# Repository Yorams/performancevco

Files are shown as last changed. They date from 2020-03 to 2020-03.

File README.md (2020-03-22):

# Performance VCO
Eurorack version of LMNC Performance VCO based on the AS3340 VCO IC

Link to original project: https://www.lookmumnocomputer.com/projects#/1222-performance-vco

Included is also the BOM with Farnell order codes and the links from the original project.

If you are intrested in ordering some PCB's for a small price i can help you with that. Send me an email: yscheer@gmail.com

You can get the arduino firmware for the tuner here: https://github.com/josbouten/Tune-O-Matic

# Some Images
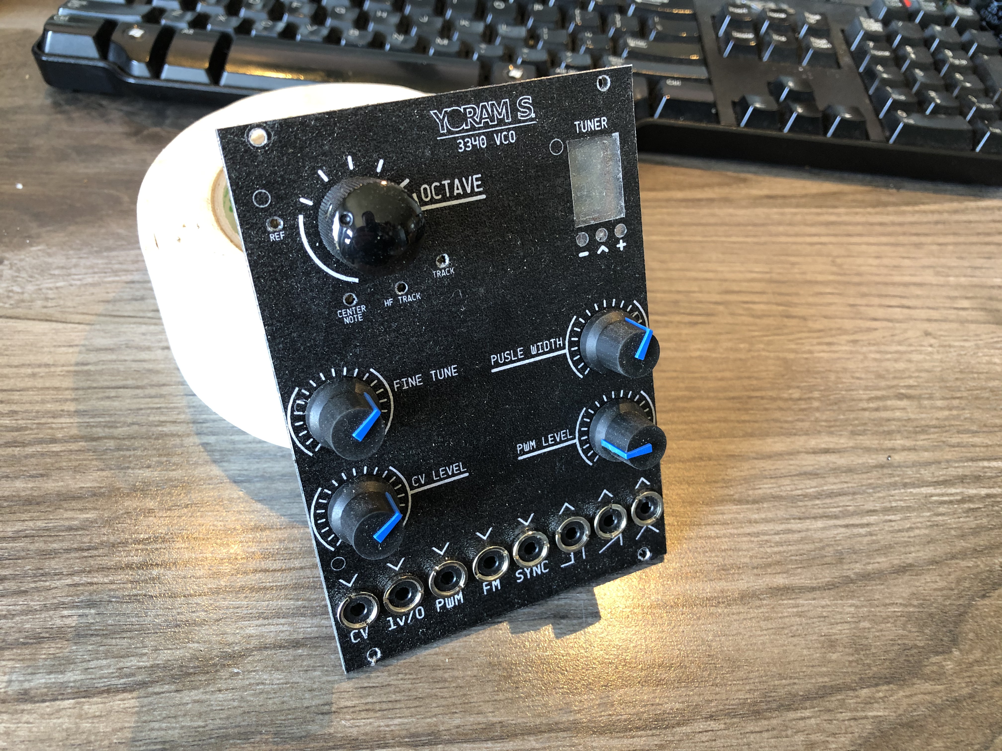
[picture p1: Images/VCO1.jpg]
VCO 1

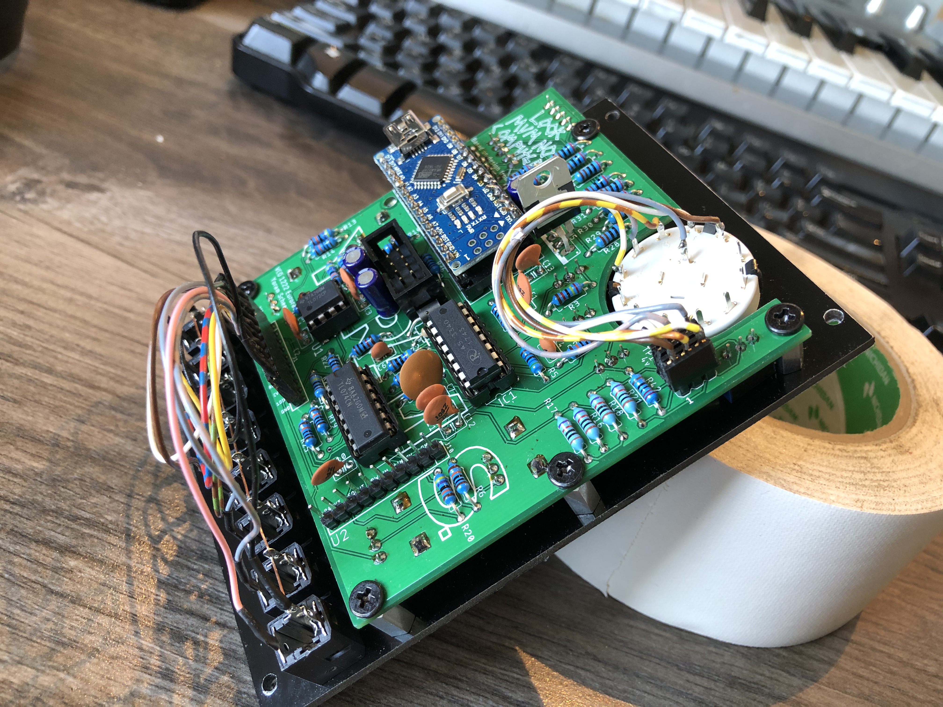
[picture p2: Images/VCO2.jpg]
VCO 2

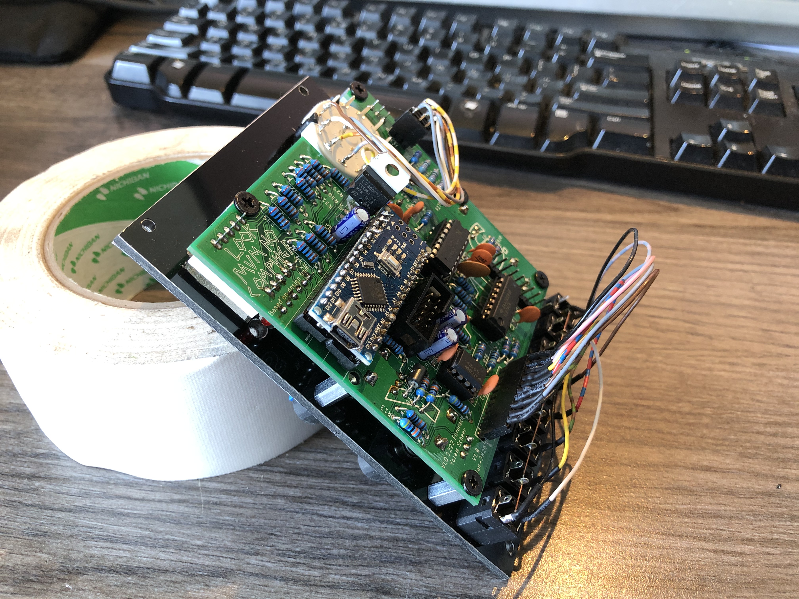
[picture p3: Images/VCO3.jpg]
VCO 3

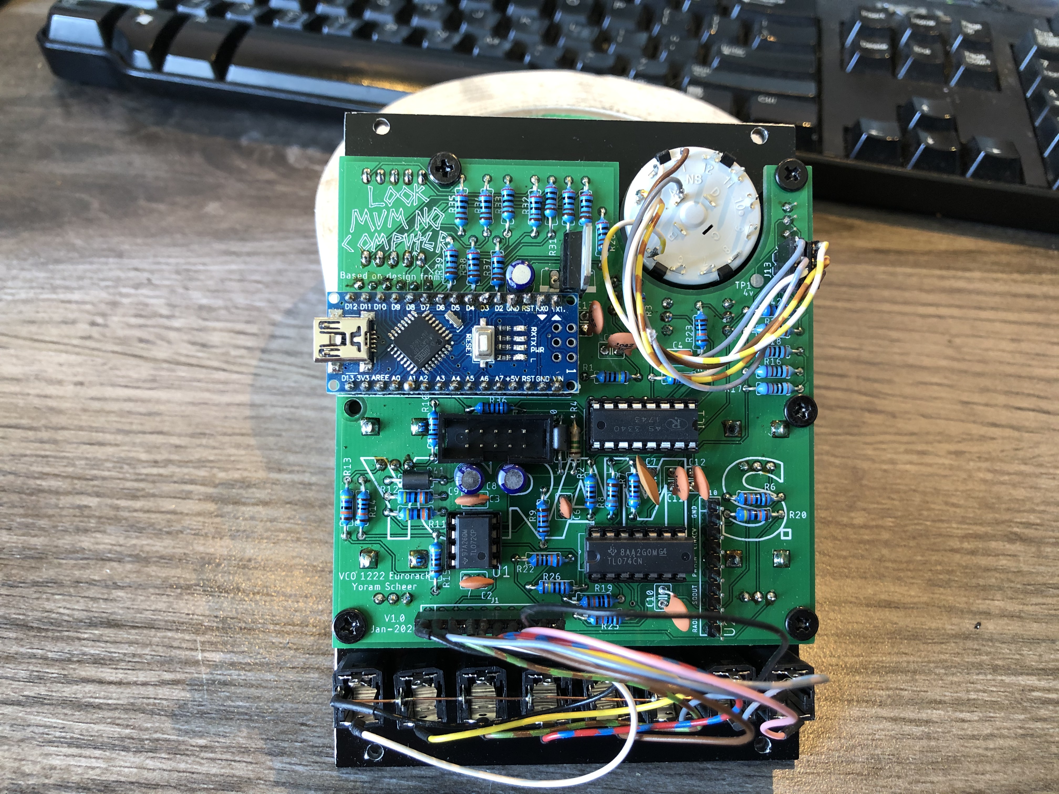
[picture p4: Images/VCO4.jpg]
VCO 4


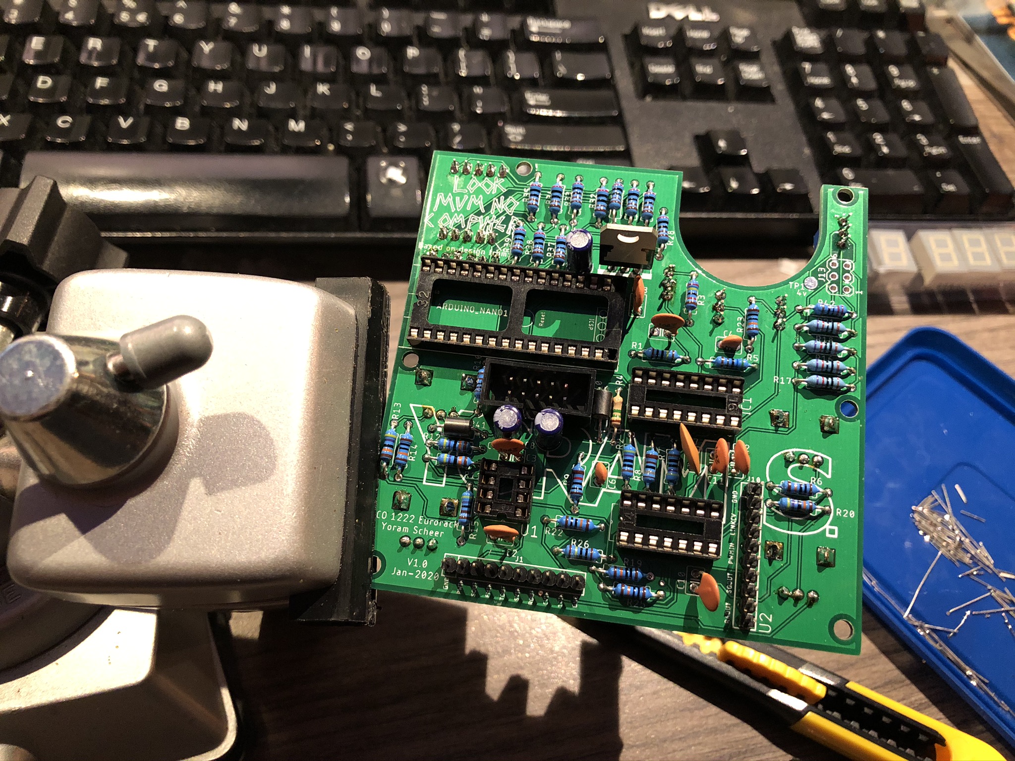
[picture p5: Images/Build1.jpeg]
Build 1

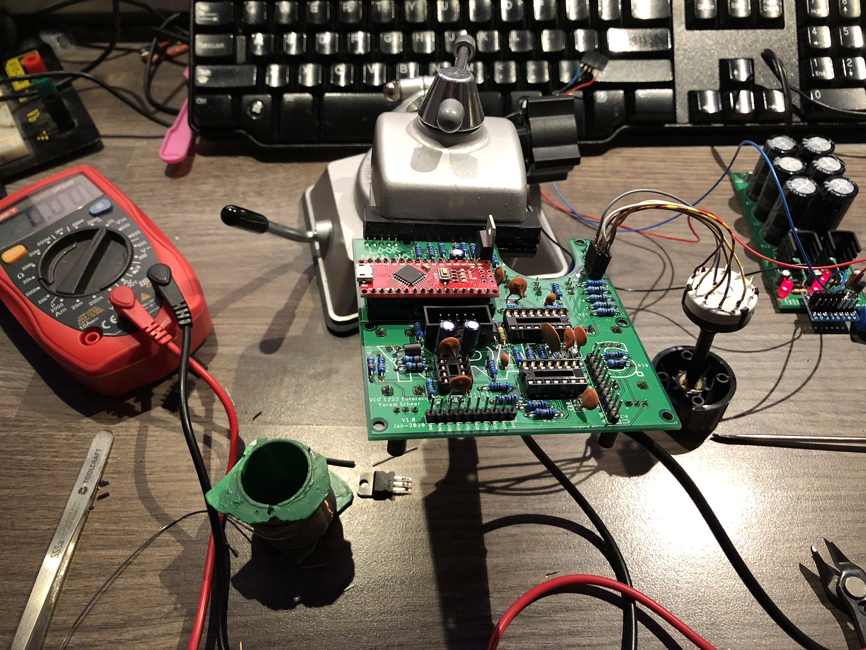
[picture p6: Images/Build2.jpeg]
Build 2

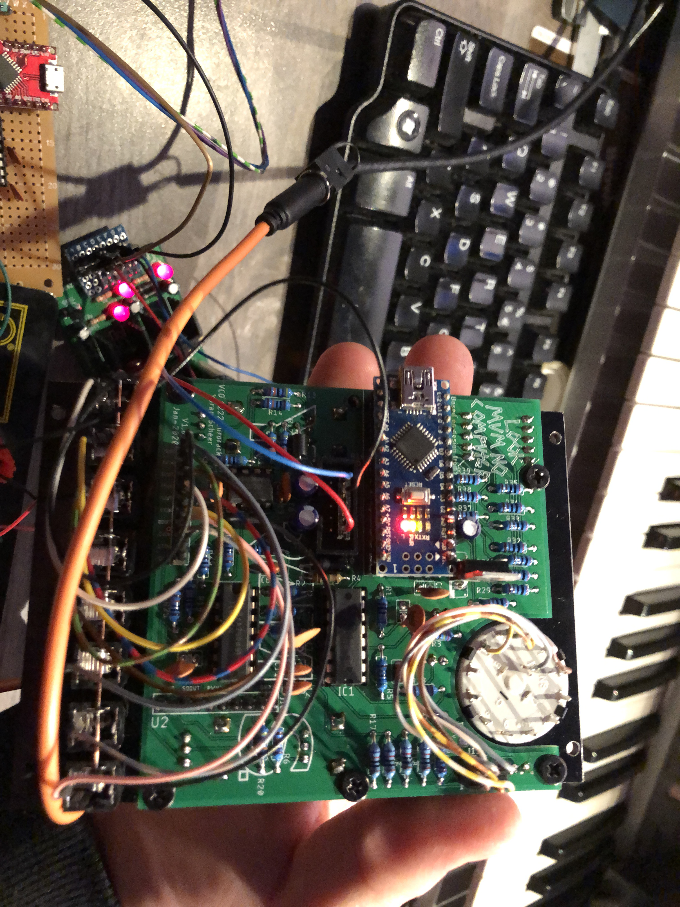
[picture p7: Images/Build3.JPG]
Build 3


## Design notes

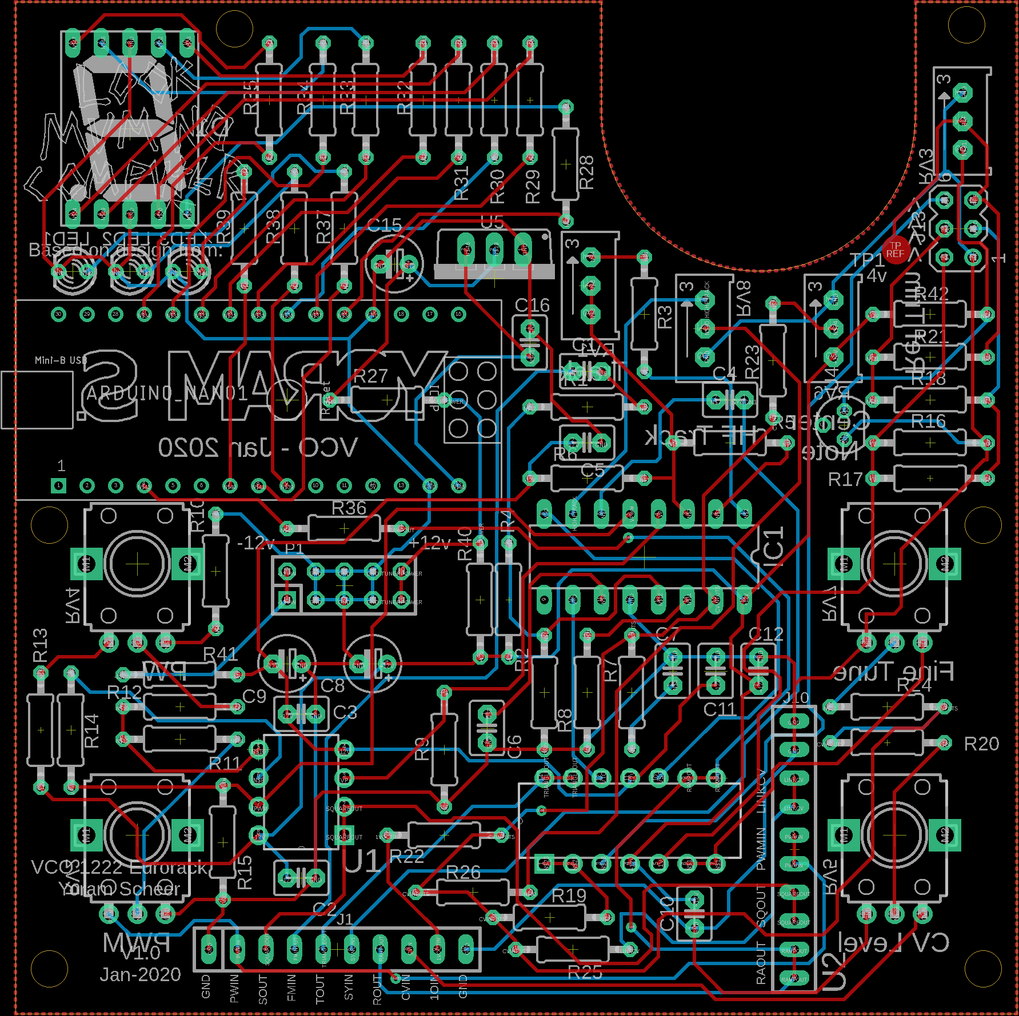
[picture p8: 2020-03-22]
Board.png

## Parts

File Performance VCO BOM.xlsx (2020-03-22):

Designator | Description | Amount | Value | Farnell code |  | Alternative supplier
C4,C6 | Ceramic Capacitor | 2 | 1nf | 9411828 |  | https://www.rapidonline.com/suntan-ts15001h102ksbpa0r-1nf-10-50v-y5p-2-5mm-ceramic-disc-capacitor-08-0200
C7 | Ceramic Capacitor | 1 | 10nf | 1827843 |  | https://www.rapidonline.com/suntan-ts15001h102ksbpa0r-1nf-10-50v-y5p-2-5mm-ceramic-disc-capacitor-08-0200
C1,C2,C3,C5,C10,C11,C12,C16 | Ceramic Capacitor | 8 | 100nf | 9411887 |  | https://www.rapidonline.com/suntan-ts15001e104msbfbor-100nf-20-25v-5mm-y5v-ceramic-disc-capacitor-08-0235
C8,C9,C15 | Electrolytic Capacitor | 3 | 10uf | 9693548 |  | https://www.rapidonline.com/forever-10uf-20-16v-85-c-7mm-micro-miniature-radial-aluminium-electrolytic-11-0825
D1,D2,D3 | 3mm LED’s 2 red 1 green, or whatever its up to you! | 3 | LED | 1142517 | 1142502 | https://www.rapidonline.com/kingbright-l-424hdt-3mm-2-25v-red-led-cylindrical-56-0300
DS1 | display! SC56-11EWA | 1 | SC56-11EWA | 1142441 |  | https://www.rapidonline.com/kingbright-sc56-11ewa-14-2mm-high-efficiency-red-led-display-cathode-57-0127
R27 | Resistor (preferable metal film 0.25W) | 1 | 100R | 9341099 |  | https://www.ebay.co.uk/itm/1280pcs-Metal-Film-Resistors-Assortment-Kit-Set-64-Values-1-10M-ohm-1-4W-UK/372820956458
R42 | Resistor (preferable metal film 0.25W) | 1 | 220R | 9341528
R2,R7 | Resistor (preferable metal film 0.25W) | 2 | 470R | 9341943
R6 | Resistor (preferable metal film 0.25W) | 1 | 680R | 9342150
R10,R36 | Resistor (preferable metal film 0.25W) | 2 | 1K | 9341102
R8 | Resistor (preferable metal film 0.25W) | 1 | 1.8k | 9341439
R28,R29,R30,R31,R32,R33,R34,R35,R37,R38,R39 | Resistor (preferable metal film 0.25W) | 11 | 2K | 9341480
R15 | Resistor (preferable metal film 0.25W) | 1 | 4k7 | 9341951
R5 | Resistor (preferable metal film 0.25W) | 1 | 5K6 | 9342060
R3 | Resistor (preferable metal film 0.25W) | 1 | 24K | 9341609
R9 | Resistor (preferable metal film 0.25W) | 1 | 10k/47k | 9341110
R14,R19,R22,R23,R24,R25 | Resistor (preferable metal film 0.25W) | 6 | 100K | 9341129
R11,R12,R13,R20 | Resistor (preferable metal film 0.25W) | 4 | 470K | 9341978
R1,R26 | Resistor (preferable metal film 0.25W) | 2 | 1M | 9341137
R4 | Resistor (preferable metal film 0.25W) | 1 | 1M5 | 1186237
R16,R18,R21,R17 | Resistor (preferable metal film 0.25W) precision.. watch vid | 4 | 10k | 1083362 |  | https://www.rapidonline.com/arcol-mra0207-10kbta15-10k-0-1-15ppm-precision-metal-film-resistor-63-2305
RV1 | Potentiometer_Vertical preset pot | 1 | 10k Vertical Preset Pot | 9353186 |  | https://www.rapidonline.com/suntan-tsr-3296w-103r-10k-wr3296w-10-3-8-cermet-trimmer-pot-68-1946
RV3,RV6 | Potentiometer_Vertical preset pot | 2 | 100k Vertical Preset Pot | 9353194 |  | https://www.rapidonline.com/suntan-tsr-3296w-104r-100k-wr3296w-10-3-8-cermet-trimmer-pot-68-1949
RV8 | Potentiometer_Vertical preset pot | 1 | 20k Vertical Preset Pot | 9353240 |  | https://www.rapidonline.com/suntan-tsr-3296w-203r-20k-wr3296w-10-3-8-cermet-trimmer-pot-68-1947
RV2,RV4,RV5,RV7 | Potentiometer_pcb mount style I use 6.35mm round shaft, up to you | 4 | Potentiometer B100k Linear | 1191742 |  | https://www.thonk.co.uk/shop/alpha-9mm-pots/
U1 | 14 pin IC quad opamp | 1 | TL074 | 3005126 |  | https://www.rapidonline.com/Catalogue/Search?Query=tl074&Size=20
A1 | Arduino_Nano , linked is a real one, you can get away with a cheap one | 1 | ARDUINO NANO |  |  | https://www.rapidonline.com/arduino-nano-a000005-board-v3-73-4448
U2 | 8 pin IC dual opamp | 1 | TL072 | 3117788 |  | https://www.rapidonline.com/Catalogue/Search?Query=tl072&Size=20
U3 | 16 pin IC VCO chip read more on my site page on this matter | 1 | AS3340/CEM3340 |  |  | https://www.thonk.co.uk/shop/curtis-cem3340-ic-vco-chip/
U5 | TO-220 package 5v voltage regulator | 1 | L7805 | 9756078 |  | https://www.rapidonline.com/st-l7805cv-5v-1a-voltage-regulator-47-3290
U4 | TO-92_Inline_Wide precision voltage regulator | 1 | LM4040AIZ 4.1 | 3124413 |  | https://www.ebay.co.uk/itm/Texas-Instruments-LM4040AIZ-4-1-NOPB-Fixed-Shunt-Voltage-Reference-4-1V-0-1/113344333366
R40,R41 | Ferrite cores, if you aint fussy like me just use some wire! | 2 | FERRITE | 9526820 |  | https://www.rapidonline.com/murata-bl01rn1-a62-axial-ferrite-bead-inductor-26-4860
J1 | Multicomp_MC9A12-1034_2x05_P2.54mm_Vertical | 1 | POWER INPUT | 2215304 |  | https://www.rapidonline.com/truconnect-10-way-idc-straight-boxed-header-2-54mm-pitch-19-0033
J11 | PinHeader_1x12_P2.54mm_Vertical | 1 | PCB INTERCONNECT MAIN |  |  | https://www.rapidonline.com/truconnect-single-row-header-36-way-pcb-plug-22-0545
 |  |  |  |  |  | https://www.rapidonline.com/truconnect-10-way-single-row-pcb-socket-2-54mm-pitch-19-0085
J12 | Multicomp_MC9A12-1034_2x05_P2.54mm_Vertical | 1 | LINK | 2215304 |  | https://www.rapidonline.com/truconnect-10-way-idc-straight-boxed-header-2-54mm-pitch-19-0033
J13 | Molex connector (I used pin headers for this) | 1 | Conn_01x06_Male | 9731172 |  | https://www.rapidonline.com/molex-22-27-2061-6-way-2-54mm-kk-straight-header-22-0846
 |  |  |  |  |  | https://www.rapidonline.com/molex-22-27-2061-6-way-2-54mm-kk-straight-header-22-0846
 |  |  |  |  |  | https://www.rapidonline.com/rvfm-ht-225d-ratchet-action-crimp-tool-ht225d-85-0262
 |  |  |  |  |  | https://www.rapidonline.com/jyk-h2500-06-6-pole-crimp-housing-22-0925
Rotary switch | 12 Way Rotary Switch single pole | 1 | Octave | 1123694 |  | https://www.rapidonline.com/taiwan-alpha-sr2611f011238f5bdnl-break-before-make-rotary-switch-1-pole-12-way-79-0220
M3 bolt 20mm and nut | This is to add rigidity | 1
Knobs |  | 4 |  | 3052360 |  | https://www.rapidonline.com/sci-rn-117b-arrow-control-knob-23mm-32-0250
 |  | 1 |  | 1209771 | 1209820 | https://www.rapidonline.com/sci-rn-114b-arrow-control-knob-37mm-32-0120
Ic sockets |  |  |  | 2668404 |  | https://www.rapidonline.com/-tube-34-truconnect-14-pin-dil-socket-7-62mm-no-central-support-tube-22-0108
 |  |  |  | 2668408 |  | https://www.rapidonline.com/-tube-60-truconnect-8-pin-dil-socket-7-62mm-no-central-support-22-0107
 |  |  |  | 2668405 |  | https://www.rapidonline.com/-tube-30-truconnect-16-pin-dil-socket-7-62mm-no-central-support-22-0109
 |  |  |  | 1182595 |  | https://www.rapidonline.com/-tube-15-truconnect-32-pin-dil-socket-15-24mm-no-central-support-22-0116
Power cable | A video on how to make them to come |  |  |  |  | https://www.thonk.co.uk/shop/eurorack-power-cables/

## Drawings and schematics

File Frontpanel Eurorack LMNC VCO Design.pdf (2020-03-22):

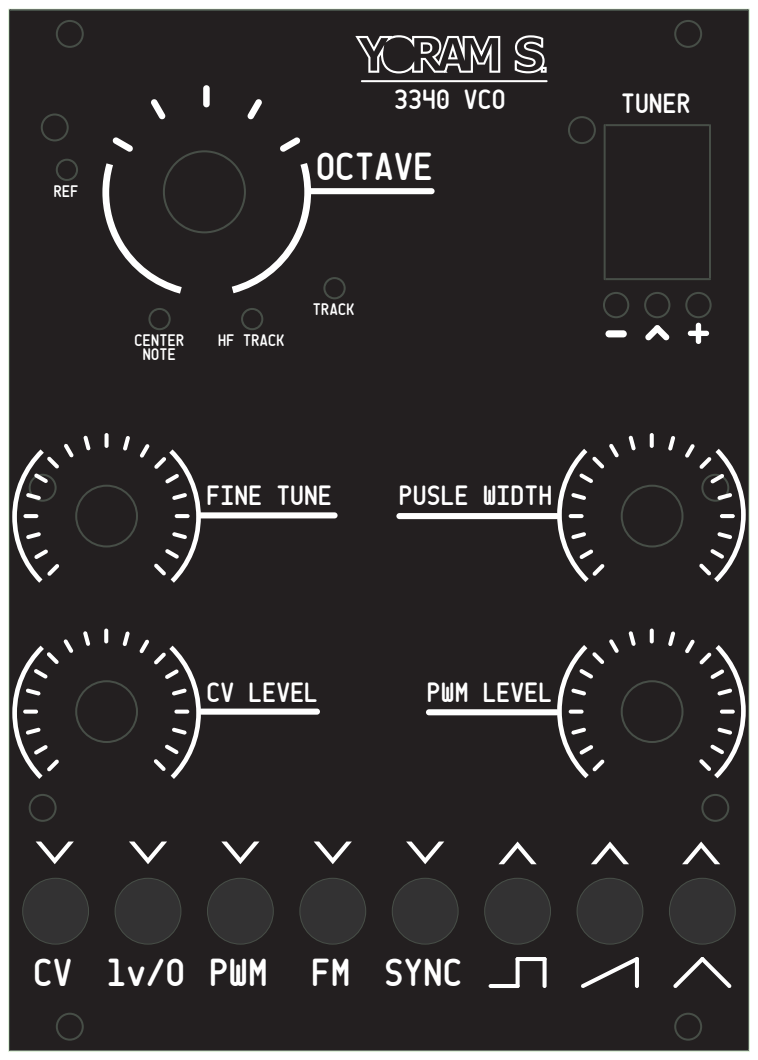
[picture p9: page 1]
TUNER; OCTAVE; CV LEVEL; FINE TUNE; PUSLE WIDTH; PWM LEVEL; 3340 VCO; TRACK; REF; CENTER; NOTE; HF TRACK

1v/O PWM FM SYNC

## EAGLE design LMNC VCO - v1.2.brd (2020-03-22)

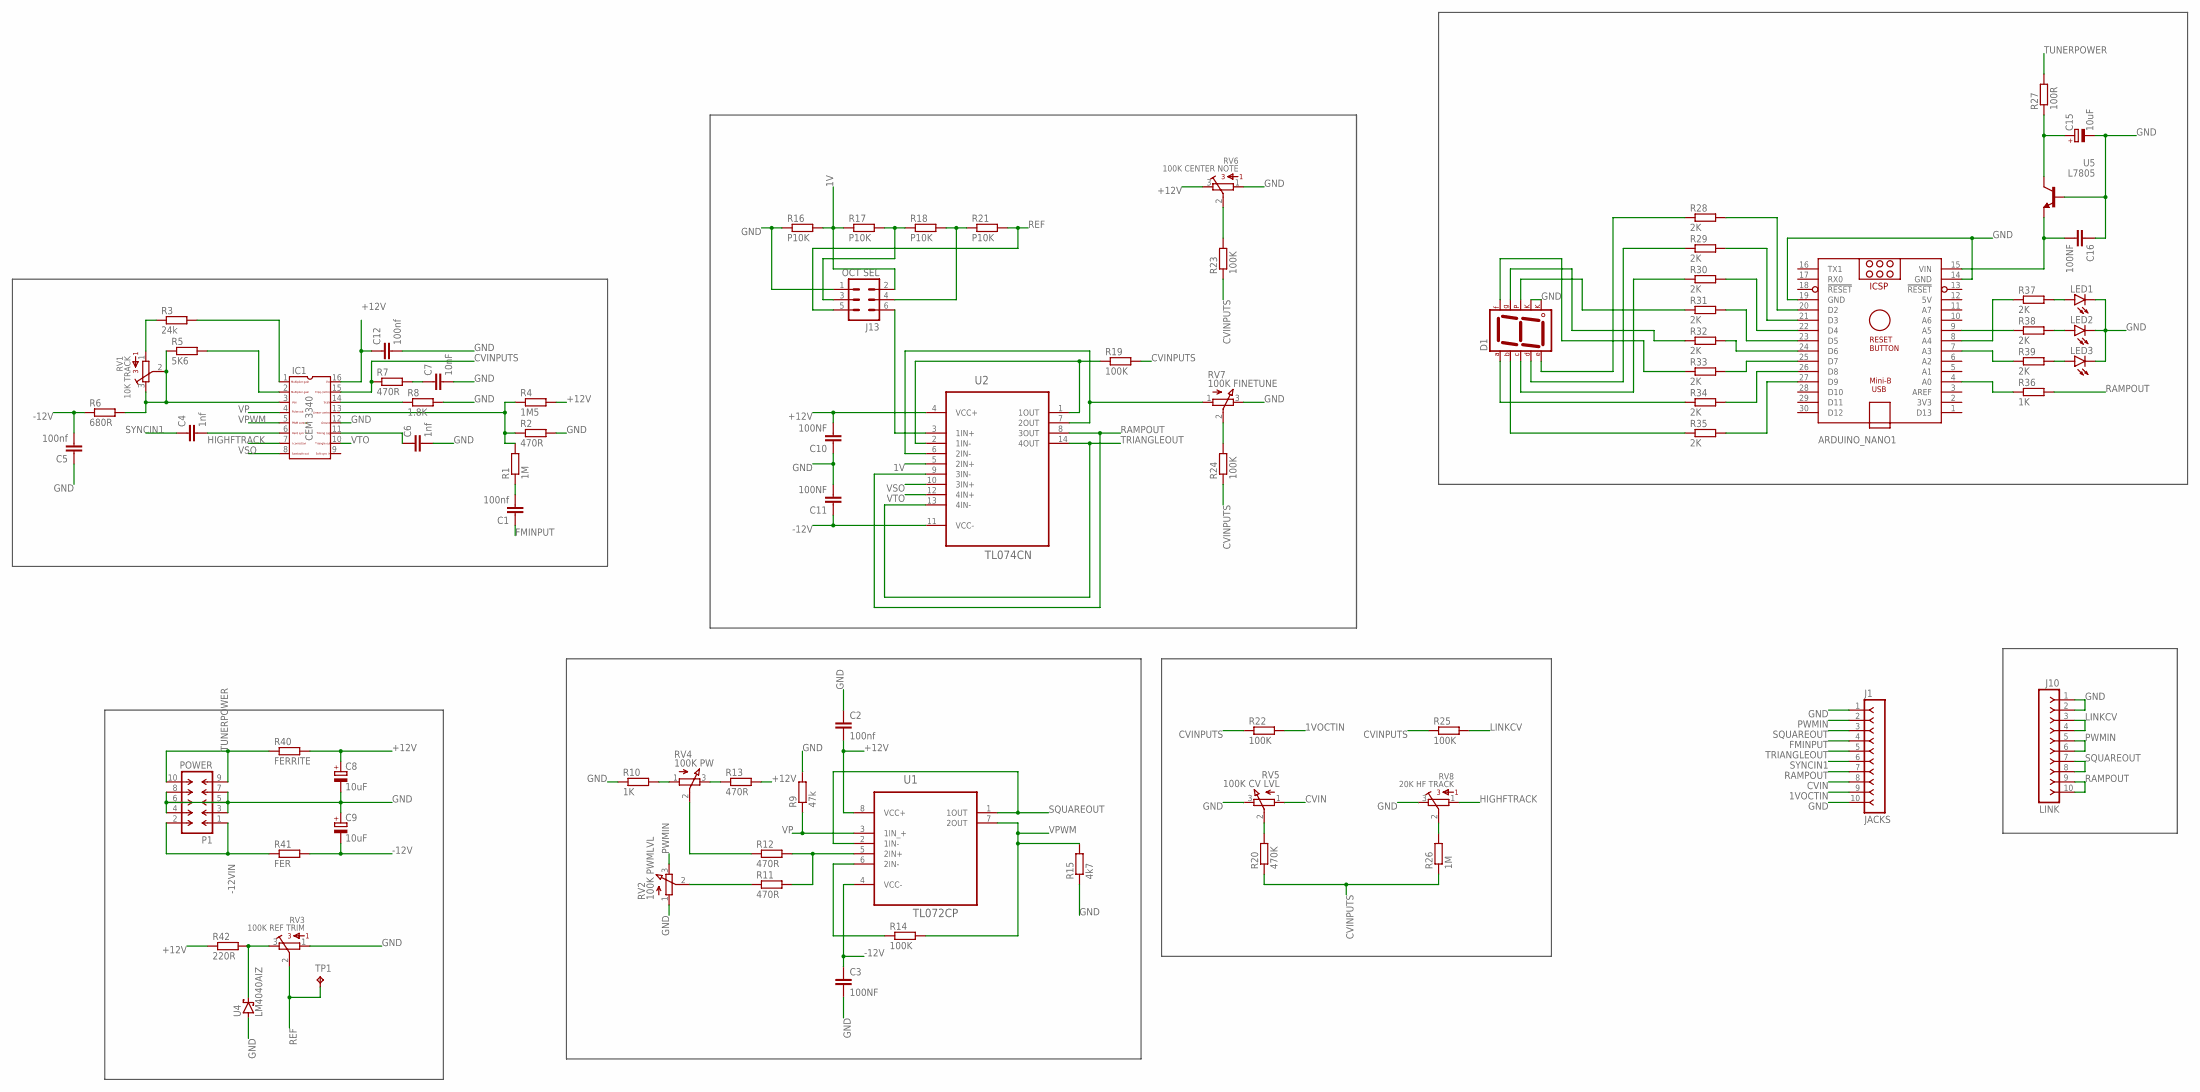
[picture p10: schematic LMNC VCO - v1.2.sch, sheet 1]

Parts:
ARDUINO_NANO1: ARDUINO_NANO
C1, C2, C5, C12: 100nf; C2.5-3
C3, C10, C11, C16: 100NF; C2.5-3
C4, C6: 1nf; C2.5-3
C7: 10nF; C2.5-3
C8, C9, C15: 10uF; E2,5-5
D1: 7SEG-CK; 7SEG-13
IC1: CEM3340; DIL16
J1: JACKS; SIP-100-10-32Y
J10: LINK; SIP-100-10-32Y
J13: OCT SEL; MA03-2
LED1, LED2, LED3: LED3MM
P1: POWER; DIL-100-2X05
R1, R26: 1M; 0207/10
R2, R7, R11, R12, R13: 470R; 0207/10
R3: 24k; 0207/10
R4: 1M5; 0207/10
R5: 5K6; 0207/10
R6: 680R; 0207/10
R8: 1.8K; 0207/10
R9: 47k; 0207/10
R10, R36: 1K; 0207/10
R14, R19, R22, R23, R24, R25: 100K; 0207/10
R15: 4k7; 0207/10
R16, R17, R18, R21: P10K; 0207/10
R20: 470K; 0207/10
R27: 100R; 0207/10
R28, R29, R30, R31, R32, R33, R34, R35, R37, R38, R39: 2K; 0207/10
R40: FERRITE; 0207/10
R41: FER; 0207/10
R42: 220R; 0207/10
RV1: 10K TRACK; 3386W
RV2: 100K PWMLVL; EVUF
RV3: 100K REF TRIM; 3386W
RV4: 100K PW; EVUF
RV5: 100K CV LVL; EVUF
RV6: 100K CENTER NOTE; 3386W
RV7: 100K FINETUNE; EVUF
RV8: 20K HF TRACK; 3386W
TP1: 4v; B2,54
U1: TL072CP; DIP254P762X508-8
U2: TL074CN; DIP254P762X508-14
U4: LM4040AIZ; SOT54A
U5: L7805; TO220BV

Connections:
1V: J13.2, R16.2, R17.1, U2.5 (2IN+)
1VOCTIN: J1.9, R22.2
5V: ARDUINO_NANO1.12 (5V)
+12V: C2.2, C8.+, C10.2, C12.1, IC1.16, R4.2, R13.2, R40.2, R42.1, RV6.3, U1.8 (VCC+), U2.4 (VCC+)
-12V: C3.1, C5.2, C9.-, C11.1, R6.1, R41.2, U1.4 (VCC-), U2.11 (VCC-)
-12VIN: P1.1, P1.2, R41.1
CVIN: J1.8, RV5.1 (A)
CVINPUTS: IC1.15, R7.1, R19.2, R20.1, R22.1, R23.1, R24.1, R25.1, R26.1
FMINPUT: C1.1, J1.4
GND: ARDUINO_NANO1.14 (GND), ARDUINO_NANO1.19 (GND), C2.1, C3.2, C5.1, C6.2, C7.2, C8.-, C9.+, C10.1, C11.2, C12.2, C15.-, C16.1, D1.3 (CK1), D1.8 (CK2), IC1.12, J1.1, J1.10, J10.1, J10.2, J13.1, LED1.K (C), LED2.K (C), LED3.K (C), P1.3, P1.4, P1.5, P1.6, P1.7, P1.8, R2.2, R8.2, R9.2, R10.1, R15.1, R16.1, RV2.1 (A), RV3.1, RV5.3 (E), RV6.1, RV7.3 (E), RV8.3, U4.A1 (A), U5.1 (B)
HIGHFTRACK: IC1.7, RV8.1
LINKCV: J10.3, J10.4, R25.2
unnamed: IC1.2, R5.2
unnamed: IC1.1, R3.2
unnamed: IC1.3, R5.1, R6.2, RV1.2, RV1.3
unnamed: R3.1, RV1.1
unnamed: C7.1, R7.2
unnamed: C1.2, R1.1
unnamed: C4.2, IC1.6
unnamed: C6.1, IC1.11
unnamed: R14.1, U1.6 (2IN-)
unnamed: R11.2, R12.2, U1.5 (2IN+)
unnamed: IC1.14, R8.1
unnamed: IC1.13, R1.2, R2.1, R4.1
unnamed: R12.1, RV4.2 (S)
unnamed: R11.1, RV2.2 (S)
unnamed: R10.2, RV4.1 (A)
unnamed: R13.1, RV4.3 (E)
unnamed: RV7.1 (A), U2.6 (2IN-), U2.7 (2OUT)
unnamed: J13.6, U2.3 (1IN+)
unnamed: C15.+, R27.1, U5.2 (C)
unnamed: J13.3, R17.2, R18.1
unnamed: J13.4, R18.2, R21.1
unnamed: R24.2, RV7.2 (S)
unnamed: R19.1, U2.1 (1OUT), U2.2 (1IN-)
unnamed: R23.2, RV6.2
unnamed: ARDUINO_NANO1.24 (D6), R32.2
unnamed: R20.2, RV5.2 (S)
unnamed: R26.2, RV8.2
unnamed: R42.2, RV3.3, U4.A2 (C)
unnamed: ARDUINO_NANO1.25 (D7), R33.2
unnamed: ARDUINO_NANO1.26 (D8), R34.2
unnamed: ARDUINO_NANO1.27 (D9), R35.2
unnamed: ARDUINO_NANO1.23 (D5), R31.2
unnamed: ARDUINO_NANO1.22 (D4), R30.2
unnamed: ARDUINO_NANO1.21 (D3), R29.2
unnamed: ARDUINO_NANO1.20 (D2), R28.2
unnamed: ARDUINO_NANO1.9 (A5), R38.1
unnamed: ARDUINO_NANO1.7 (A3), R39.1
unnamed: ARDUINO_NANO1.8 (A4), R37.1
unnamed: LED1.A, R37.2
unnamed: LED2.A, R38.2
unnamed: LED3.A, R39.2
unnamed: ARDUINO_NANO1.4 (A0), R36.1
unnamed: ARDUINO_NANO1.15 (VIN), C16.2, U5.3 (E)
unnamed: D1.6 (B), R35.1
unnamed: D1.7 (A), R34.1
unnamed: D1.4 (C), R30.1
unnamed: D1.2 (D), R29.1
unnamed: D1.1 (E), R28.1
unnamed: D1.9 (F), R33.1
unnamed: D1.10 (G), R32.1
unnamed: D1.5 (DP), R31.1
PWMIN: J1.2, J10.5, J10.6, RV2.3 (E)
RAMPOUT: J1.7, J10.9, J10.10, R36.2, U2.8 (3OUT), U2.9 (3IN-)
REF: J13.5, R21.2, RV3.2, TP1.TP
SQUAREOUT: J1.3, J10.7, J10.8, U1.1 (1OUT), U1.2 (1IN-)
SYNCIN1: C4.1, J1.6
TRIANGLEOUT: J1.5, U2.13 (4IN-), U2.14 (4OUT)
TUNERPOWER: P1.9, P1.10, R27.2, R40.1
VP: IC1.4, R9.1, U1.3 (1IN_+)
VPWM: IC1.5, R14.2, R15.2, U1.7 (2OUT)
VSO: IC1.8, U2.10 (3IN+)
VTO: IC1.10, U2.12 (4IN+)

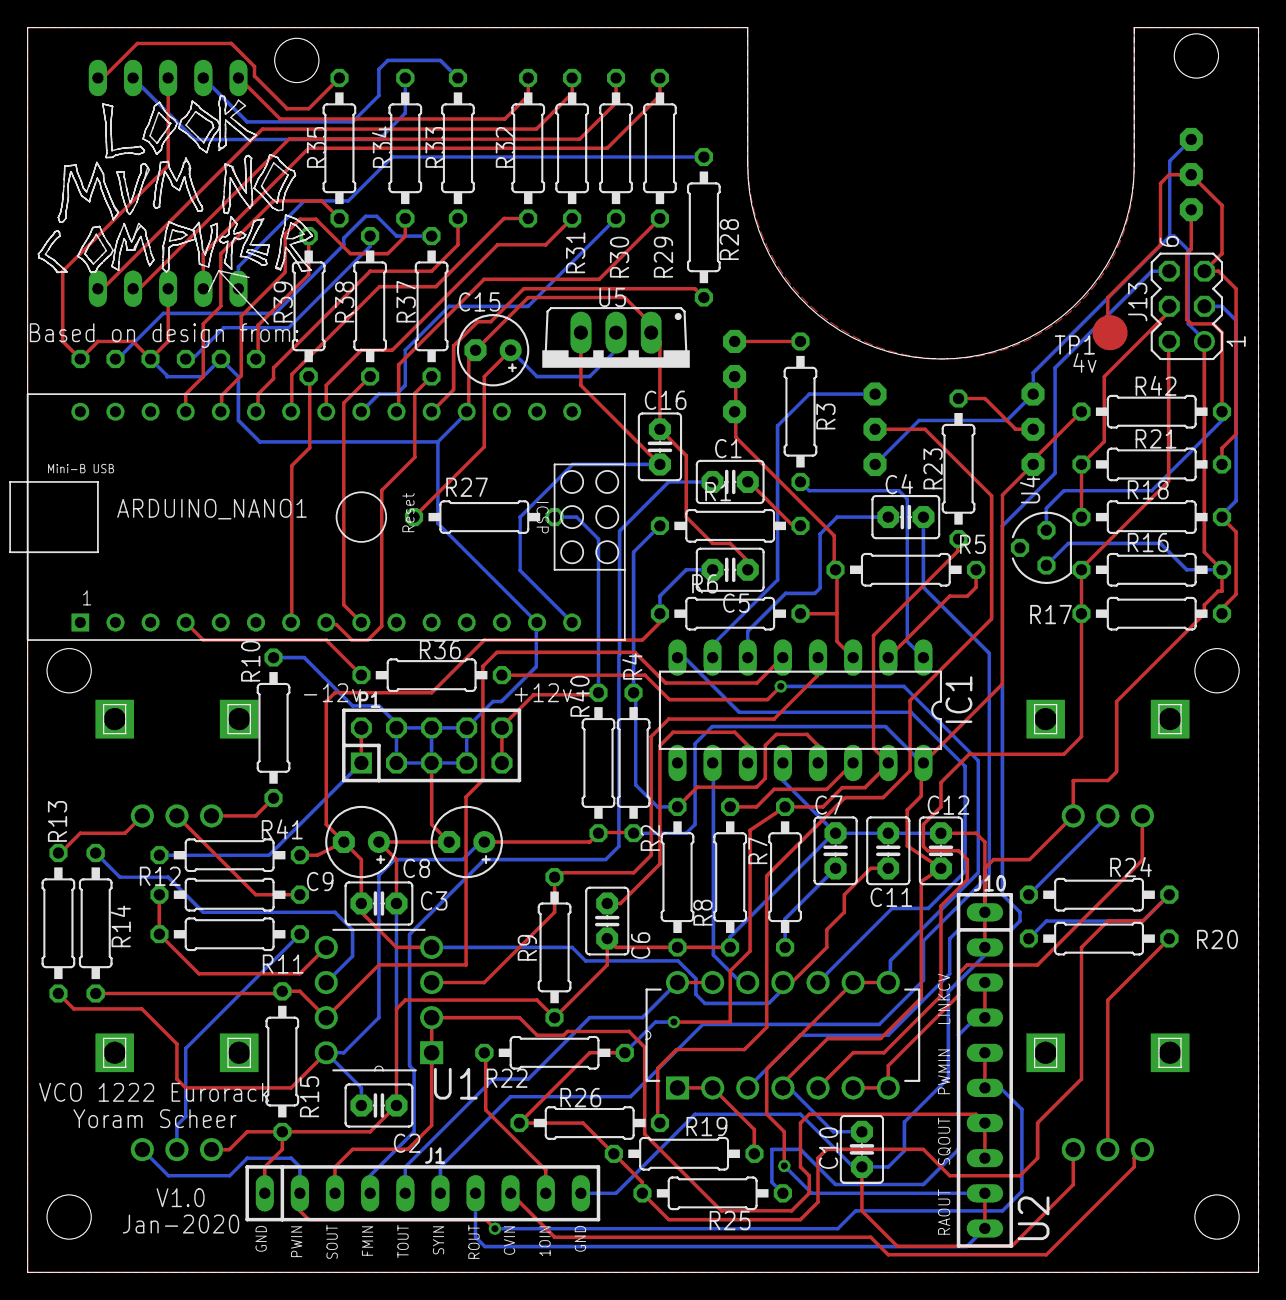
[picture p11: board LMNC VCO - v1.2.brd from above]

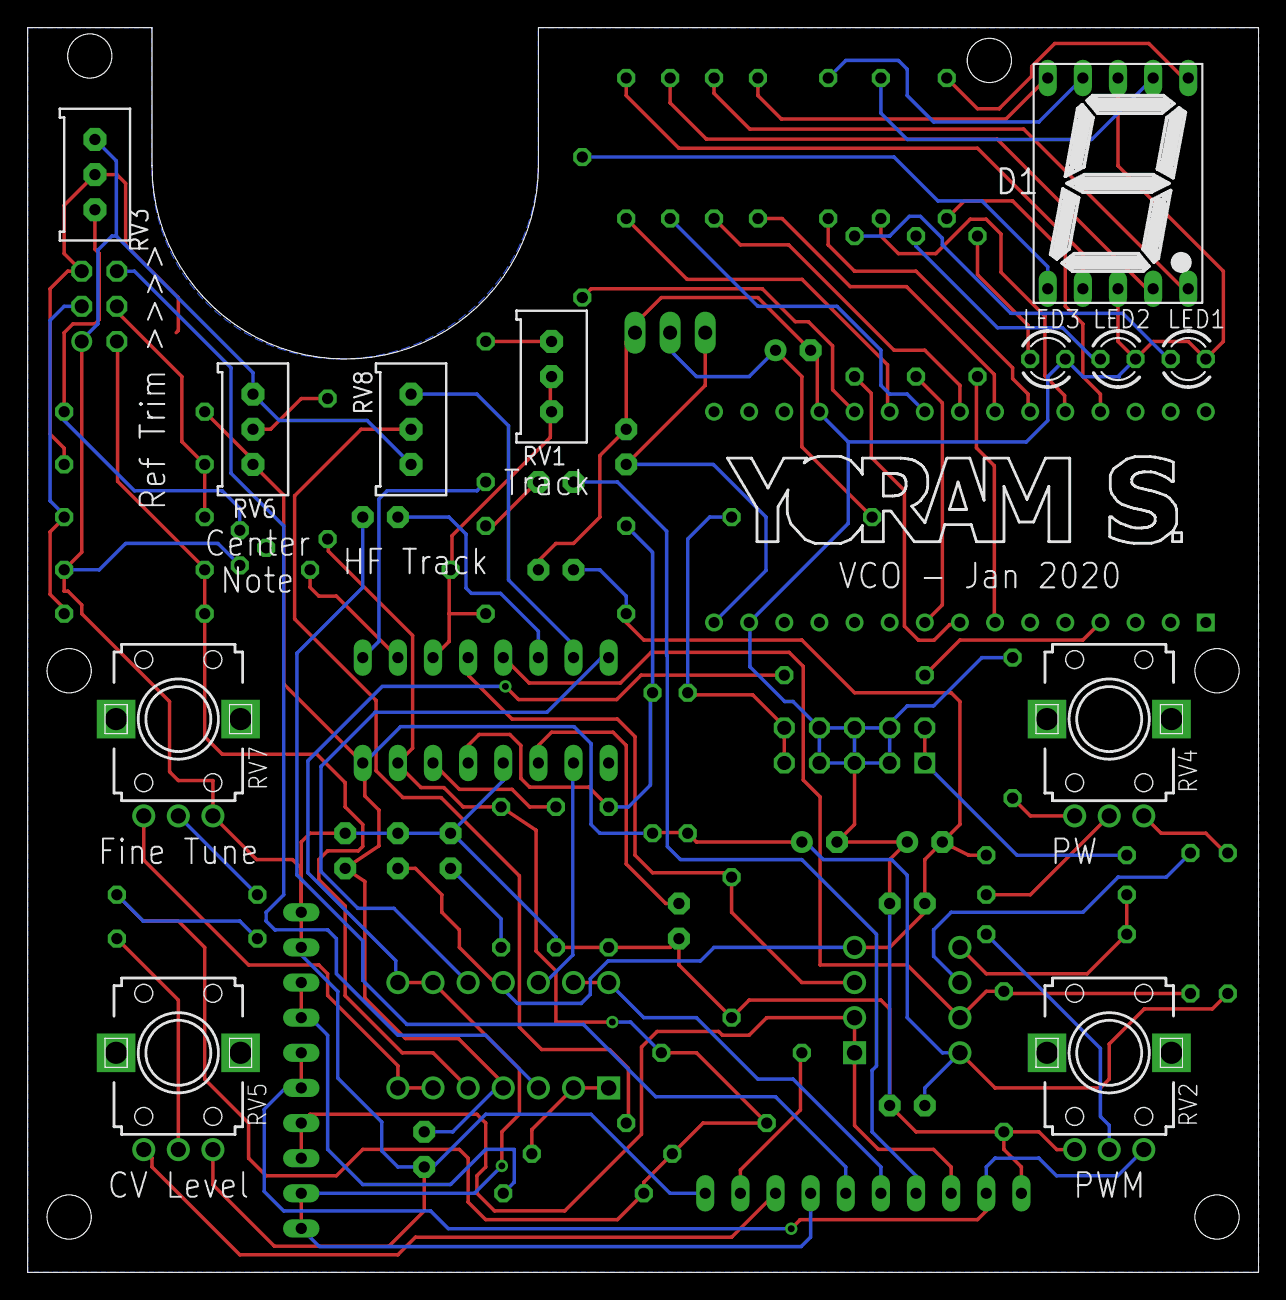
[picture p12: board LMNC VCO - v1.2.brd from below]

Board: 2 copper layers, 89.0 x 90.0 mm, 79 parts (12 on the bottom side), 73 nets.

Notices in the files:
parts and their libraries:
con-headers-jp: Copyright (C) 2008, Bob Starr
